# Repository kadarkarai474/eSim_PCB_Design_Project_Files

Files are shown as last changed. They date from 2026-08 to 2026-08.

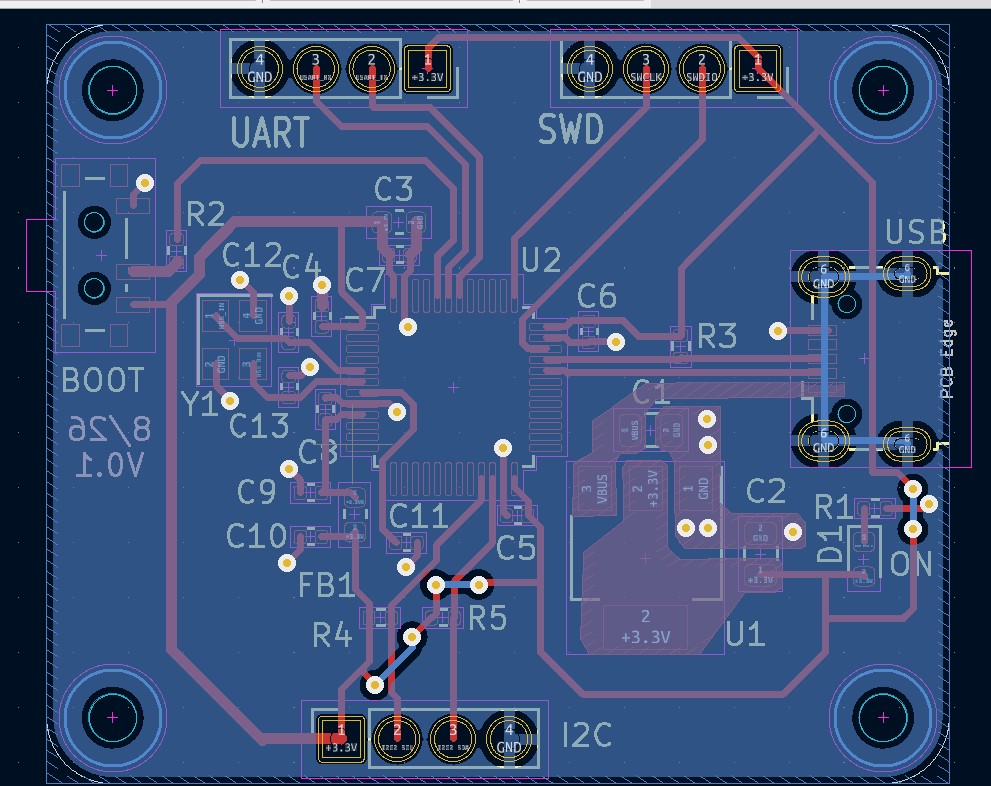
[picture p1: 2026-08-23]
PCB_IMAGES/Screenshot 2026-08-23 191847.jpg

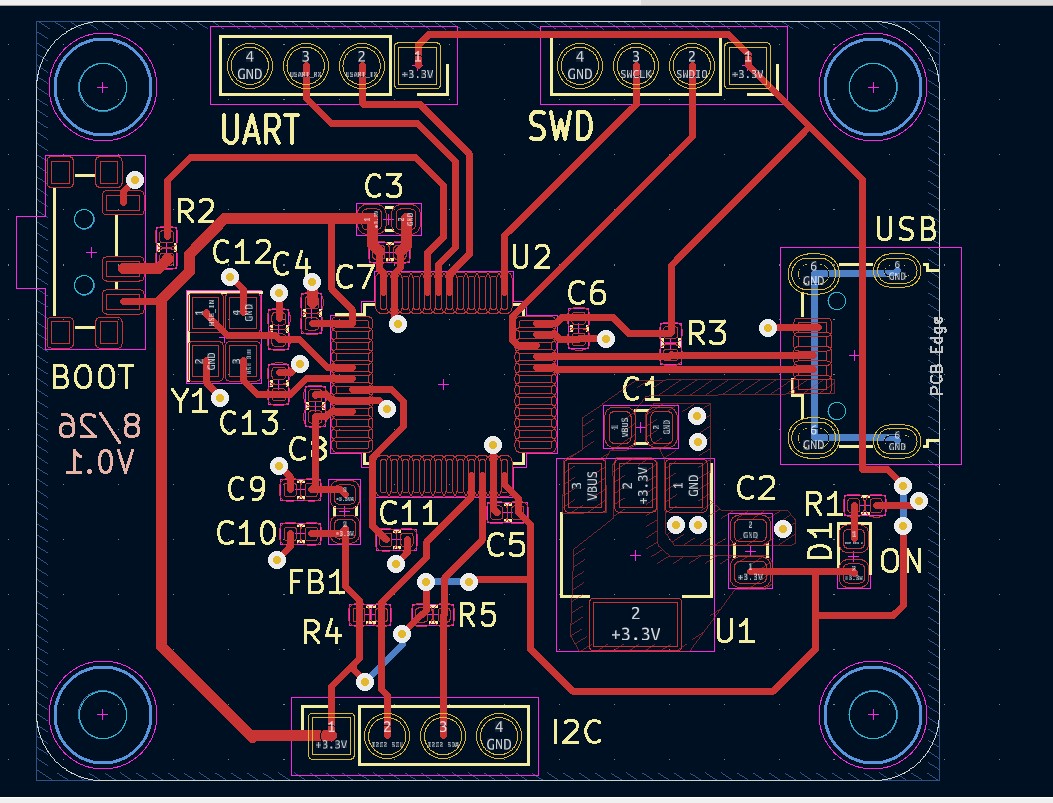
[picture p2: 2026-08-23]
PCB_IMAGES/Screenshot 2026-08-23 191208.jpg

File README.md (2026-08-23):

# STM32BASE — Custom STM32F103C8T6 USB Development and Multi-Interface Controller Board

## 1. Project Title

**STM32BASE: Custom STM32F103C8T6 USB Development and Multi-Interface Controller Board**

## 2. Project Abstract

STM32BASE is a compact, custom-designed STM32 microcontroller development and embedded-control board developed as a reusable hardware platform for embedded systems, IoT, robotics, instrumentation, and digital control applications. The board is centered around the **STM32F103C8T6 ARM Cortex-M3 microcontroller** and integrates regulated 3.3 V power, USB connectivity, UART communication, I²C expansion, SWD programming/debugging, boot-mode selection, external clock generation, status indication, and dedicated decoupling/filtering.

The proposed design converts the functionality normally distributed across a commercial STM32 development board, USB-to-serial interface board, and separate programming/debugging headers into a single custom PCB. The STM32F103 family provides high-performance processing with operation up to 72 MHz and peripherals including USB, USART, SPI, I²C, ADC, timers/PWM and CAN, making the platform suitable for extending the present design with additional communication and control interfaces.

The PCB is designed with attention to component placement, power distribution, short high-speed signal paths, grounding, decoupling, footprint selection, routing quality, and manufacturability. The current implementation is a **two-layer PCB**, satisfying the FOSSEE eSim PCB Design requirement of at least two copper layers; a future four-layer revision could further improve power/ground integrity and may receive additional consideration under the current Autumn 2026 evaluation criteria.

## 3. Problem Statement

Commercial STM32 development boards are convenient for prototyping but often contain unnecessary circuitry, limited connector options, and a fixed board architecture. For embedded development and PCB-design education, there is a need for a compact custom controller board that exposes essential MCU interfaces while demonstrating the complete engineering workflow from schematic capture to PCB layout, routing, DRC verification, and 3D visualization.

**STM32BASE addresses this requirement by providing a reusable custom STM32 platform with integrated programming, communication, power, clock, boot and expansion interfaces on a single PCB.**

## 4. Main Objectives

1. Design a functional custom STM32F103C8T6-based controller PCB.
2. Implement a stable **5 V to 3.3 V regulated power architecture**.
3. Provide direct USB connectivity for power and USB communication.
4. Provide dedicated UART, I²C and SWD connectors.
5. Implement a reliable external clock using an 8 MHz crystal.
6. Provide BOOT-mode selection for firmware programming and recovery.
7. Implement proper MCU decoupling and filtered power distribution.
8. Demonstrate practical PCB layout and routing techniques.
9. Perform electrical and design-rule verification before fabrication.
10. Develop the complete project using the eSim-compatible PCB workflow required by FOSSEE.

## 5. Functional Block Description

**USB / 5 V Input → Power Regulation → 3.3 V Digital Supply → STM32F103C8T6**

The MCU provides the central processing function and connects to:

**USB Interface → USB D+/D−**

**UART Header → Serial Communication**

**I²C Header → Sensor/Peripheral Expansion**

**SWD Header → Programming and Debugging**

**BOOT Selector → Firmware Boot Configuration**

**8 MHz Crystal → External Clock Reference**

**LED → Power/Status Indication**

## 6. Key Design Parameters

| Parameter | Proposed Design |
| --- | --- |
| Project Name | STM32BASE |
| MCU | STM32F103C8T6 |
| MCU Architecture | ARM Cortex-M3 |
| Maximum MCU Clock | Up to 72 MHz for STM32F103 performance-line devices |
| MCU Supply | 3.3 V nominal |
| MCU Supply Range | STM32F103 family: 2.0–3.6 V |
| Input Supply | 5 V from USB |
| Voltage Regulator | AMS1117-3.3 |
| Regulated Output | 3.3 V |
| External Crystal | 8 MHz |
| USB | USB 2.0 Full-Speed device interface |
| Programming | SWD |
| Serial Interface | UART |
| Sensor/Expansion Interface | I²C |
| Boot Configuration | BOOT selector |
| PCB Layers | 2-layer current design |
| Future PCB Option | 4-layer revision |
| Board Type | Custom STM32 development/controller board |
| PCB Technology | SMD + through-hole connectors |
| Mounting | Four PCB mounting holes |
| Status Indication | LED indicator |
| Debug Interface | SWD header |
| Expansion | UART and I²C headers |
| Primary Application | Embedded control and rapid prototyping |

## 7. Major Components Required

| Ref. | Component | Typical Value / Part | Quantity | Function |
| --- | --- | --- | ---: | --- |
| U2 | Microcontroller | STM32F103C8T6 | 1 | Main processing/control unit |
| U1 | LDO Regulator | AMS1117-3.3 | 1 | 5 V to 3.3 V regulation |
| J1 | USB Connector | Micro-USB | 1 | Power and USB data |
| J2 | UART Header | 1×4 header | 1 | UART TX/RX and power |
| J3 | I²C Header | 1×4 header | 1 | I²C SDA/SCL and power |
| J4 | SWD Header | 1×4 header | 1 | Programming/debugging |
| Y1 | Crystal | 8 MHz | 1 | External MCU clock |
| S1 | Boot Switch | SPDT | 1 | Boot-mode selection |
| FB1 | Ferrite Bead | Power filtering type | 1 | Supply-noise isolation |
| D1 | LED | 3.3 V status/power LED | 1 | Visual indication |
| R1 | LED Resistor | 1.5 kΩ | 1 | LED current limiting |
| R2 | BOOT Resistor | 10 kΩ | 1 | BOOT0 biasing |
| R3 | USB Resistor | 1 kΩ class | 1 | USB interface support |
| R4 | I²C Pull-up | 4.7 kΩ | 1 | SDA pull-up |
| R5 | I²C Pull-up | 4.7 kΩ | 1 | SCL pull-up |
| C1/C2 | Bulk Capacitors | 10–22 µF class | 2 | Supply stabilization |
| C3–C11  | Ceramic Decoupling | 100 nF / 1 µF / 10 µF class |  Several | MCU and supply decoupling |
| C12/C13 | Crystal Capacitors | ~10–20 pF class | 2 | Crystal load capacitors |
| H1–H4 | Mounting Hardware  | PCB mounting holes | 4 | Mechanical mounting |

**Note:** The final BOM should exactly match the verified eSim schematic values before submission. Values such as the USB support resistor and capacitor values should be checked against the final schematic/netlist rather than copied only from the PCB screenshot.

## 8. Interface Specification

| Interface | Connector | Purpose | Application |
| --- | --- | --- | --- |
| USB | Micro-USB | Power + USB data | PC communication / firmware tools |
| UART | 1×4 header | Serial TX/RX | Debugging, GPS, GSM, Bluetooth modules |
| I²C | 1×4 header | SDA/SCL | Sensors, displays, EEPROMs |
| SWD | 1×4 header | Programming/debugging | STM32 programmer/debugger |
| BOOT | SPDT switch | Boot configuration | Firmware recovery/programming |
| GPIO | MCU expansion capability | Digital control | LEDs, relays, sensors |
| ADC | MCU internal | Analog measurement | Sensors/potentiometers |
| PWM | MCU timers | Actuator control | Motors, LEDs, servos |

The STM32F103 family natively supports USB, USART, SPI, I²C, ADC, timers/PWM and CAN, providing a strong path for expanding this base platform into a more capable universal controller.

## 9. Power-Supply Architecture

The power section accepts **5 V from the USB connector** and generates a regulated **3.3 V rail** using an AMS1117-3.3 regulator.

| Stage | Component | Voltage | Purpose |
| --- | --- | ---: | --- |
| Input | USB VBUS | 5 V | External power source |
| Filtering | C1/C2 + FB1 | 5 V | Reduce supply disturbances |
| Regulation | AMS1117-3.3 | 3.3 V | MCU supply generation |
| Local Decoupling | Ceramic capacitors | 3.3 V | Suppress high-frequency noise |
| MCU Supply | STM32F103C8T6 | 3.3 V | Core and I/O supply |

The regulated 3.3 V supply is appropriate for the STM32F103 family, whose specified supply range is 2.0–3.6 V.

## 10. Clock and Reset Architecture

The design includes an **8 MHz external crystal oscillator** with dedicated load capacitors connected to the STM32 oscillator pins. The MCU can use its internal PLL to derive the required system clock from the external clock source.

The clock section is intentionally placed close to the MCU to reduce unnecessary trace length and susceptibility to noise.

The design also includes the required boot-selection circuitry, allowing the user to select normal firmware execution or the appropriate boot/programming mode.

## 11. PCB Design Features

The PCB layout shown in the design incorporates:

* Dedicated MCU placement near the center of the board.
* Compact placement of crystal and oscillator capacitors near the MCU.
* Dedicated USB connector at the board edge.
* Separate SWD and UART headers for convenient debugging.
* I²C expansion connector for external peripherals.
* Local decoupling capacitors surrounding the MCU.
* Separate power-regulation section.
* Ferrite filtering for supply-noise isolation.
* Clearly identifiable component reference designators.
* Four mechanical mounting holes.
* Ground and power routing designed around the major functional blocks.

## 12. PCB Routing Strategy

| Design Area | Routing Strategy |
| --- | --- |
| 3.3 V Power | Short, low-resistance power paths |
| MCU Decoupling | Capacitors placed as close as practical to supply pins |
| Crystal | Very short oscillator connections |
| USB | Short and symmetric D+/D− routing |
| SWD | Direct routing between MCU and debug header |
| UART | Direct low-speed signal routing |
| I²C | Pull-up resistors located on the interface section |
| Ground | Continuous/low-impedance ground strategy |
| USB Entry | Connector positioned at PCB edge |
| High-activity Signals | Kept away from sensitive clock section |
| Mechanical | Components kept clear of mounting-hole regions |

## 13. Important PCB Design Parameters

| Parameter | Design Target |
| --- | --- |
| PCB Layer Count | 2 layers |
| Recommended Future Version | 4 layers |
| Board Shape | Compact rectangular |
| Mounting Holes | 4 |
| Main PCB Material | FR-4 |
| Copper | Standard PCB copper |
| Component Technology | Predominantly SMD |
| Connectors | Through-hole/SMD depending on selected footprint |
| Ground Strategy | Dedicated ground routing/pour |
| DRC | Zero critical errors targeted |
| Routing | Complete connectivity |
| Silkscreen | Component identification and interface labels |
| 3D Verification | Required |
| Footprint Verification | Required |
| Manufacturing Readiness | Required |

## 14. Design Complexity

The project is more than a basic microcontroller breakout because it combines multiple hardware subsystems on a single custom PCB:

| Subsystem | Complexity |
| --- | --- |
| STM32 MCU integration | Medium |
| USB interface | Medium |
| 3.3 V power supply | Medium |
| External clock | Medium |
| BOOT configuration | Low–Medium |
| SWD programming | Low |
| UART expansion | Low |
| I²C expansion | Low |
| Power filtering | Medium |
| High-density MCU routing | High |
| Compact PCB placement | High |
| DRC and manufacturability | High |
| Complete eSim → PCB → 3D workflow | High |

This makes STM32BASE a **medium-to-hard complexity PCB project**, while remaining realistic to fabricate and demonstrate.

## 15. Advantages of the Proposed Design

1. **Custom rather than module-based:** The STM32 MCU is directly placed on the PCB instead of using a prebuilt development module.
2. **Integrated programming:** SWD is available directly on the board.
3. **USB-enabled:** A dedicated USB connector removes the need for an external USB interface board.
4. **Multiple communication interfaces:** UART and I²C are directly accessible.
5. **Dedicated power architecture:** USB input and regulated 3.3 V distribution are integrated.
6. **Expandable:** Unused STM32 peripherals can be exposed in future revisions.
7. **Educational value:** Demonstrates schematic design, footprint selection, power design, PCB placement, routing, DRC and 3D verification.
8. **Reusable platform:** The board can become the base controller for robotics, sensor nodes, automation systems and IoT prototypes.

## 16. Suggested Future Enhancements

To make a future revision more advanced and competitive, the following can be added:

| Enhancement | Benefit |
| --- | --- |
| CAN transceiver | Automotive/industrial communication |
| SPI header | High-speed peripheral expansion |
| Additional GPIO headers | External module integration |
| ADC expansion header | Analog sensor interfacing |
| PWM header | Motor/servo control |
| 5 V output | External module power |
| ESD protection on USB | Improved robustness |
| Reverse-polarity protection | Safer external power |
| Reset/user push button | Improved user interaction |
| Additional status LEDs | Easier debugging |
| USB ESD protection | Better USB reliability |
| 4-layer PCB | Improved power/ground integrity and routing density |
| Dedicated ground plane | Better return-current control |
| Test points | Easier laboratory debugging |

## 17. FOSSEE eSim PCB Design Relevance

This project directly demonstrates the workflow expected for the current FOSSEE eSim PCB Design task: schematic development, footprint assignment, PCB generation, routing, DRC verification and 3D visualization. The Autumn 2026 task specifies a minimum of two copper layers and notes that boards with a higher layer count may receive additional consideration. It also evaluates design complexity, footprint assignment, layout quality, routing practices, DRC validation, eSim compatibility and documentation quality.

The final submission should therefore document the complete design flow rather than presenting only the finished PCB.

## 18. Expected Deliverables

| Deliverable | Contents |
| --- | --- |
| Schematic | Complete STM32BASE circuit |
| PCB | Routed PCB layout |
| Project Files | Complete eSim/KiCad-compatible project |
| BOM | Components, values, quantities and footprints |
| Schematic Images  | Annotated circuit diagrams |
| PCB Images | Top/bottom/layout views |
| 3D Images | Final PCB 3D visualization |
| DRC Report | Verification and corrected errors |
| Design Report | Architecture, design decisions and results |
| Execution Guide | Steps to open and verify the project |
| GitHub Repository | Organized project source and documentation |

FOSSEE's current Autumn 2026 PCB-design instructions specifically require a detailed PDF report, complete eSim project workspace, instructions for opening/verifying the project, and optionally a short presentation or demonstration.

## 19. Proposed Applications

STM32BASE can be used as the central controller for:

* IoT sensor nodes
* Industrial monitoring
* Robotics controllers
* Motor-control prototypes
* Environmental monitoring
* Data acquisition systems
* Smart automation
* Embedded instrumentation
* Communication gateways
* Educational STM32 development
* Custom sensor and actuator platforms

## 20. Conclusion

**STM32BASE is a compact custom STM32 development and controller platform that integrates the essential hardware required for embedded development into a single PCB.** The design combines a regulated 3.3 V power system, STM32F103C8T6 microcontroller, USB connectivity, UART, I²C, SWD programming, external clock, BOOT control, filtering, status indication and mechanical mounting into one reusable board.

The project provides substantial PCB-design content while remaining technically manageable: the evaluator can clearly observe the schematic architecture, power design, footprint selection, dense MCU routing, interface placement, DRC verification and final 3D implementation. It is therefore a strong candidate for an eSim/FOSSEE PCB Design submission, with a clear path toward a more advanced four-layer revision incorporating CAN, SPI, additional GPIO/PWM/ADC expansion and improved protection circuitry.

### Recommended Final Project Name

**STM32BASE – Custom STM32F103C8T6 USB Multi-Interface Development and Control Board**

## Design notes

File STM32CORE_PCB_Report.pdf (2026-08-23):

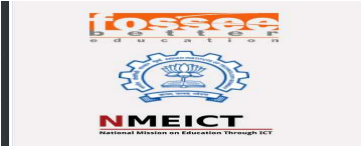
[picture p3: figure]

## FOSSEE 2026 - SEMESTER LONG INTERNSHIP

## INTERNSHIP SCREENING TASK REPORT

### Task 7 — PCB Design using eSim KICAD

## Prepared by Kadarkarai V, II Year

## Department of VLSI Design and Technology Chennai Institute of Technology

### PROJECT: STM32BASE — Custom STM32F103C8T6 USB Development and Multi-Interface Controller Board

STM32CORE — PCB Design Report

## 1. Project Overview

This project presents the complete printed circuit board (PCB) design and schematic files for a custom STM32F103C8T6 microcontroller development and interface board, named STM32CORE. The design was developed as part of the screening task for the FOSSEE Autumn Internship 2026 program conducted by IIT Bombay.

The primary objective of this project was to design a compact, functional, and manufacturable controller board centered around the STM32F103C8T6 (Cortex-M3) microcontroller, integrating regulated power, USB connectivity, UART communication, I²C expansion, SWD programming, boot-mode selection, and an external crystal clock reference onto a single custom two-layer PCB.

Key Project Details

Category | Specification / Detail
Microcontroller | STM32F103C8T6 / STM32F103CBTx (ARM Cortex-M3, up to 72 MHz)
Design Tools | eSim 5 (schematic capture), KiCad 6 (PCB layout, integrated via eSim)
Input Supply | 5 V from USB (VBUS)
Regulated Supply | 3.3 V, via AMS1117-3.3 LDO regulator
Crystal Oscillator | 16 MHz external crystal
PCB Stackup | 2-layer (Front Copper + Back Copper)
Verification Status | Both ERC and DRC passed with zero errors
The finished design includes a fully routed two-layer PCB, verified schematic with zero ERC violations, a zero-violation DRC report, and a 3D rendered model for visual verification of component placement and mechanical fit.

## 2. Circuit Description

### 2.1 Power Supply Section

The board is powered from the 5 V USB VBUS rail and regulated down to a stable 3.3 V supply using an AMS1117-3.3 LDO regulator (U1). Bulk input and output capacitors (C1, C2 — 22 µF each) stabilise the supply on both sides of the regulator, and a status LED (D1) with a 1.5 kΩ current-limiting resistor (R1) provides visual power-on indication.

### 2.2 Clock and Reset

A 16 MHz external crystal (Y1) with a pair of 10 pF load capacitors (C12, C13) provides the primary system clock reference to the STM32F103 oscillator pins (PD0/PD1). The MCU's internal PLL derives the required core clock from this external source. A dedicated reset line (NRST) and BOOT0 configuration network (R2, SW1) allow selection between normal firmware execution and system bootloader mode for programming/recovery.

### 2.3 Connectivity and Interfaces

- Micro-USB Port (J1): USB 2.0 Full-Speed interface for power and USB D+/D− data, with a 1.5 kΩ series resistor (R3) on the data line as per USB application guidelines.
- SWD Header (J3): 4-pin header exposing SWDIO, SWCLK, 3.3 V and GND for direct on-board programming and debugging.
- UART Header (J2): 4-pin header exposing USART_TX, USART_RX, 3.3 V and GND for serial communication and debugging.
- I²C Header (J4): 4-pin header exposing I2C2_SDA, I2C2_SCL, 3.3 V and GND, with 1.5 kΩ pull-up resistors (R4, R5) for sensor and peripheral expansion.

### 2.4 Power Filtering and Decoupling

The analog supply (VDDA) is isolated from the digital 3.3 V rail using a 120 Ω ferrite bead (FB1) with local filter capacitors (C8, C9, C10), reducing high-frequency supply noise reaching the MCU's analog section. Digital decoupling is provided at the MCU supply pins using a bank of ceramic capacitors (C3–C7: 10 µF and 100 nF values) placed close to the VDD/VBAT pins.

### 2.5 Peripheral Summary

Interface | Header / Pins | Typical Application
USB | Micro-USB (J1), USB D+/D− | PC communication, firmware/programming tools
UART | J2 — USART_TX, USART_RX | Debugging, GPS, GSM, Bluetooth modules
I²C | J4 — SDA, SCL | Sensors, displays, EEPROMs
SWD | J3 — SWDIO, SWCLK | STM32 programmer / debugger
BOOT | SW1 (SPDT) + R2 | Firmware boot-mode / recovery selection

## 3. Schematic Screenshots

The complete schematic was designed in eSim 5 and organised into two logical, clearly labelled functional blocks — Power Supply and Microcontroller with USB — for clarity and maintainability.

### 3.1 Full Schematic Overview

The top-level schematic sheet (STM32BASE_DESIGN) provides a complete view of the design, showing the Power Supply block and the Microcontroller-with-USB block interconnected through labelled nets and power buses, along with the board mounting-hole reference symbols.

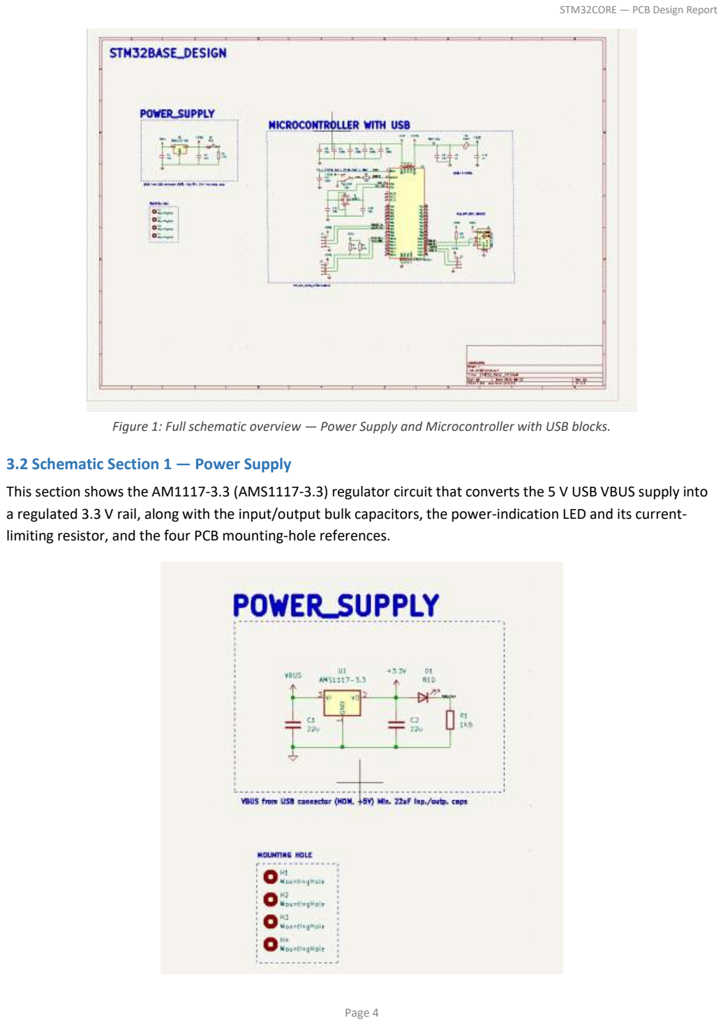
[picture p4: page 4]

Figure 1: Full schematic overview — Power Supply and Microcontroller with USB blocks.

### 3.2 Schematic Section 1 — Power Supply

This section shows the AM1117-3.3 (AMS1117-3.3) regulator circuit that converts the 5 V USB VBUS supply into a regulated 3.3 V rail, along with the input/output bulk capacitors, the power-indication LED and its current-limiting resistor, and the four PCB mounting-hole references.

Figure 2: Power Supply schematic — AMS1117-3.3 regulation and mounting-hole references.

### 3.3 Schematic Section 2 — Microcontroller with USB

This section captures the STM32F103CBTx pin assignments, the full decoupling capacitor network, the 16 MHz crystal oscillator connections, NRST/BOOT0 configuration circuitry, the VDDA filtering network, and the USB, UART and I²C interface connections — all cross-referenced against the STM32CubeIDE pin-out.

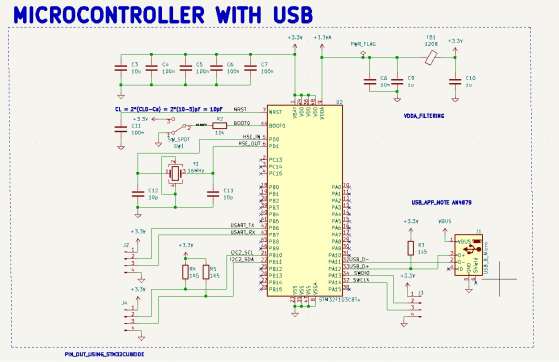
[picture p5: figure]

Figure 3: Microcontroller with USB — MCU core, clock, boot, and interface circuitry.

### 3.4 Electrical Rules Check (ERC)

The Electrical Rules Checker was run on the complete schematic in eSim/KiCad and returned zero violations, confirming that all nets, power pins, and interface connections are electrically consistent.

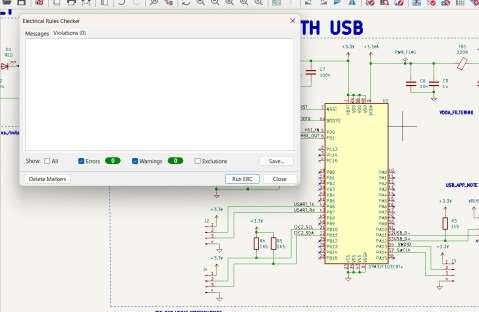
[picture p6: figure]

Figure 4: Electrical Rules Checker — 0 errors, 0 warnings.

## 4. Footprint Assignment Details

Component footprints were assigned in KiCad 6 using standard, datasheet-verified footprint libraries appropriate to each package type, ensuring correct pad geometry and courtyard clearances for fabrication.

### 4.1 Microcontroller

- Component: STM32F103C8T6 / STM32F103CBTx
- Package: LQFP-48, 7×7 mm body, 0.5 mm pin pitch

### 4.2 Passive Components

- Resistors: 0603 SMD footprint — used for pull-ups (I²C), current limiting (LED, BOOT0), and USB series termination
- Capacitors: 0603 SMD footprint — used for decoupling, bulk bypass, VDDA filtering, and crystal load capacitors
- Crystal Oscillator: SMD 2-pin/4-pin package as per component datasheet (16 MHz)

### 4.3 Connectors

- Micro-USB: Standard Micro-B USB receptacle footprint with mechanical shield/anchor pads
- Pin Headers (UART, SWD, I²C): 1×4, 2.54 mm pitch through-hole male headers

### 4.4 Power and Interface Components

- Voltage Regulator (AMS1117-3.3): SOT-223 footprint with thermal pad
- Boot Selector: SPDT slide/tactile switch footprint
- Status LED: 0603 SMD LED footprint

## 5. PCB Layout

The PCB layout was completed in KiCad 6 (accessed through eSim 5 integration) as a two-layer board, with the Front Copper (F.Cu) layer carrying the primary component-side routing and the Back Copper (B.Cu) layer used for return paths and selective routing.

### 5.1 Complete Board — Routed Layout

The routed board places the STM32F103 MCU (U2) centrally, with the crystal and its load capacitors kept close to the oscillator pins, the USB connector positioned at the board edge, and the UART, SWD and I²C headers broken out along the top and bottom edges for easy access. Four mechanical mounting holes are provided at the corners.

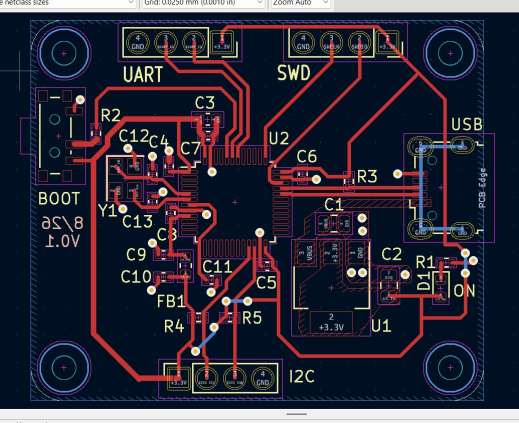
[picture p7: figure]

Figure 5: Complete routed PCB layout — top view showing UART, SWD, USB, I²C and BOOT sections.

### 5.2 Board Layout — Alternate Layer View

This view highlights the copper routing on the board with the alternate KiCad colour theme, showing the same interconnects between the MCU, power section (U1, C1, C2), filtering network (FB1, R4, R5) and the four peripheral headers.

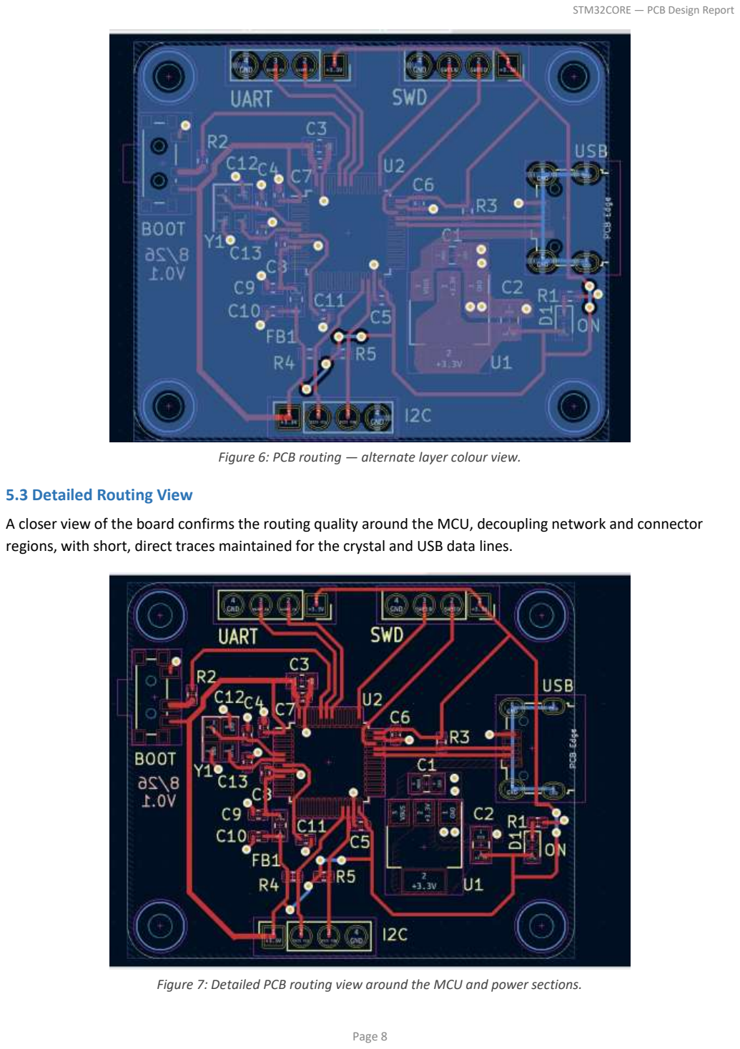
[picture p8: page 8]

Figure 6: PCB routing — alternate layer colour view.

### 5.3 Detailed Routing View

A closer view of the board confirms the routing quality around the MCU, decoupling network and connector regions, with short, direct traces maintained for the crystal and USB data lines.

Figure 7: Detailed PCB routing view around the MCU and power sections.

## 6. Routing Methodology

### 6.1 Layer Stackup

Layer | Name | Function
1 | F.Cu (Front) | Primary component-side signal routing
2 | B.Cu (Back) | Secondary routing and return paths

### 6.2 Signal Routing Guidelines

- Decoupling capacitors placed as close as physically possible to the MCU VDD/VBAT pins.
- Crystal oscillator traces routed short and direct, with the crystal and load capacitors kept close to the MCU oscillator pins to minimise parasitic capacitance.
- USB D+/D− lines routed as a short, symmetric pair from the MCU to the Micro-USB connector at the board edge.
- I²C pull-up resistors located directly at the I²C header for signal integrity.
- General signal traces routed on the front copper layer with return paths managed on the back copper layer.
- Components kept clear of the four mounting-hole regions for mechanical safety.

### 6.3 Design Rule Constraints

- Minimum trace width and spacing as per standard two-layer manufacturing capability.
- Minimum via drill size and annular ring maintained within manufacturer tolerances.
- Copper-to-edge clearance maintained around the full board outline.
- No acid traps or acute-angle traces present in the routing.

## 7. DRC Results

The Design Rules Check was performed on the completed two-layer PCB layout in KiCad 6 to verify physical manufacturability. All copper zones were refilled before running the check.

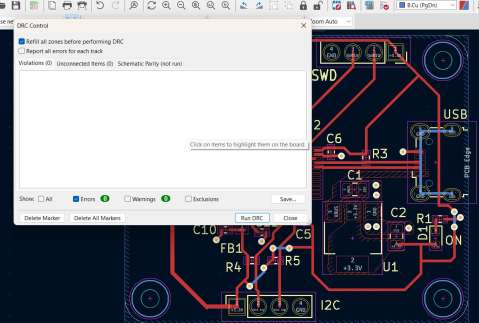
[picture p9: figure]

Figure 8: DRC Control — 0 violations, 0 unconnected items.

The DRC report confirms zero violations across errors, warnings and unconnected items, indicating that all traces, vias, clearances, and drill holes are within standard manufacturing capability.

## 8. 3D Model

The 3D model of the board was generated using KiCad's built-in 3D viewer to verify component placement accuracy, connector accessibility, and overall board form factor before committing to fabrication.

### 8.1 Front View

The front (top) view shows the primary component side of the board, with the STM32 MCU (U2) at the centre, surrounded by the crystal (Y1), decoupling capacitors, the BOOT switch, the regulator section (U1), and the UART, SWD, USB and I²C connectors clearly labelled on the silkscreen.

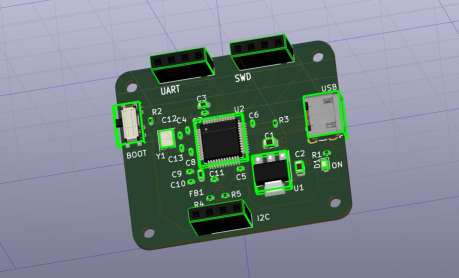
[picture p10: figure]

Figure 9: 3D model — front view with labelled interfaces.

### 8.2 Back View

The back (bottom) view shows the underside of the board, including the header through-hole pads, the version/date silkscreen marking (8/26, V0.1), and the mounting-hole positions.

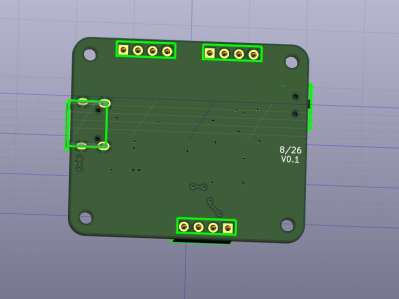
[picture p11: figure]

Figure 10: 3D model — back view.

## 9. Design Considerations and Conclusion

### 9.1 Design Considerations

Power Integrity: Bulk capacitors at the regulator input/output and a dedicated decoupling bank at the MCU supply pins keep the 3.3 V rail stable under load.

Signal Integrity: Short, direct routing for the crystal and USB data lines minimises parasitic effects and preserves clock accuracy and USB signal quality on a two-layer stackup.

Analog Isolation: The VDDA filtering network (FB1 ferrite bead with local capacitors) isolates the MCU's analog supply from digital switching noise.

Manufacturability: The design satisfies the FOSSEE eSim PCB Design requirement of a minimum of two copper layers, and passes DRC with zero errors, confirming that all features are within standard manufacturing capability.

Expandability: Unused STM32F103 peripherals (SPI, additional ADC/timer channels, CAN) remain available for a future, more advanced revision of the board.

### 9.2 Conclusion

This project successfully delivers a complete, verified PCB design for the STM32CORE development and interface board built around the STM32F103C8T6 microcontroller. The design achieves the following key outcomes:

- Fully verified design — ERC passed with zero violations, and DRC passed with zero errors and zero unconnected items.
- Compact two-layer stackup — meeting the FOSSEE eSim PCB Design minimum layer requirement while remaining realistic to fabricate.
- Comprehensive connectivity — the board exposes USB, UART, I²C and SWD through accessible headers, along with BOOT-mode selection.
- Complete documentation — schematic, PCB layout, ERC/DRC verification and 3D visualisation are all included for full design transparency.
The design demonstrates proficiency in schematic capture, PCB layout and routing, design-rule compliance, and 3D visualisation using eSim 5 and KiCad 6 — the core competencies required for the FOSSEE Autumn Internship 2026 screening task.
Designed by Kadarkarai V | Department of VLSI Design and Technology, Chennai Institute of Technology | FOSSEE Autumn
Internship 2026 — IIT Bombay

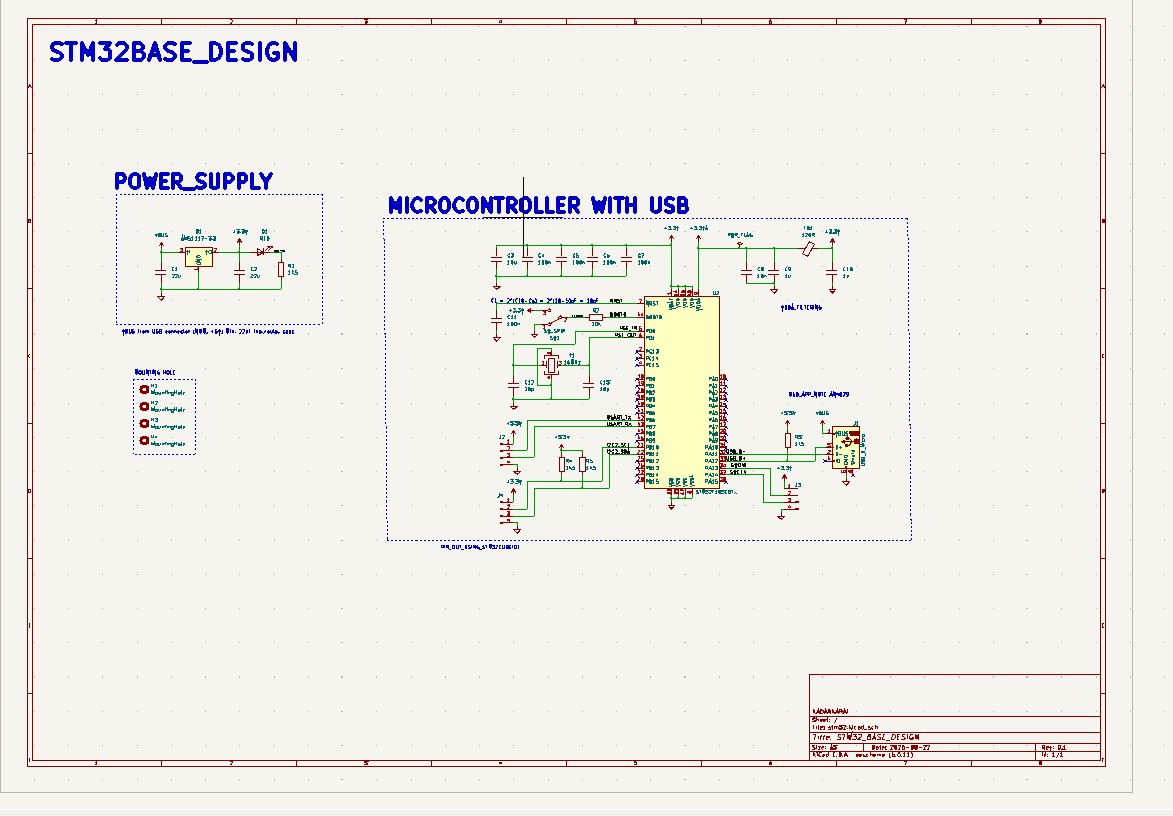
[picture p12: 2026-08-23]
PCB_IMAGES/Screenshot 2026-08-23 191109.jpg

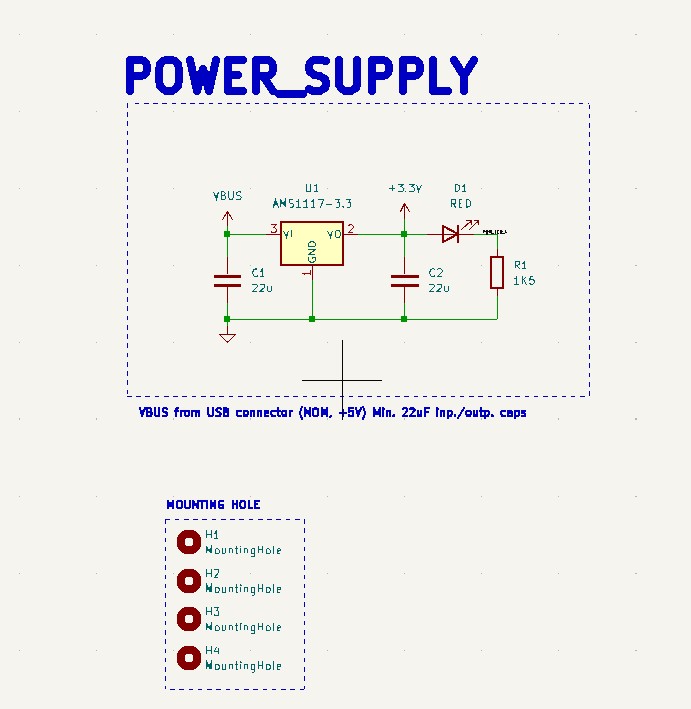
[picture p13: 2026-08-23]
PCB_IMAGES/Screenshot 2026-08-23 191127.jpg

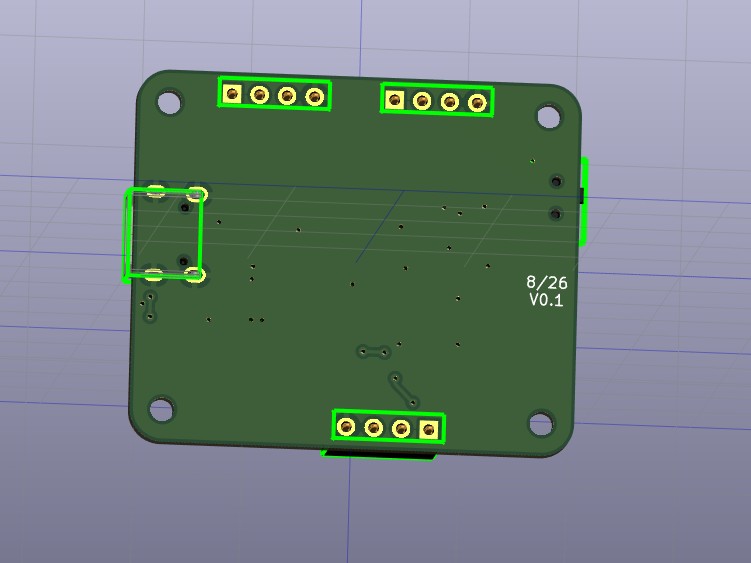
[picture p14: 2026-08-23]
PCB_IMAGES/Screenshot 2026-08-23 191251.jpg

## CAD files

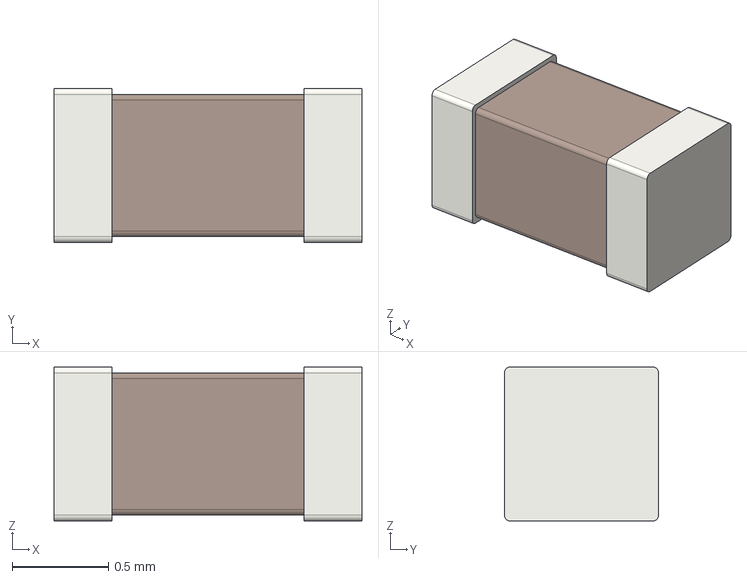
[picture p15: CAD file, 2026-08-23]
3DMODELS/C_0603_1608Metric.step
1.60 x 0.8 x 0.8 mm

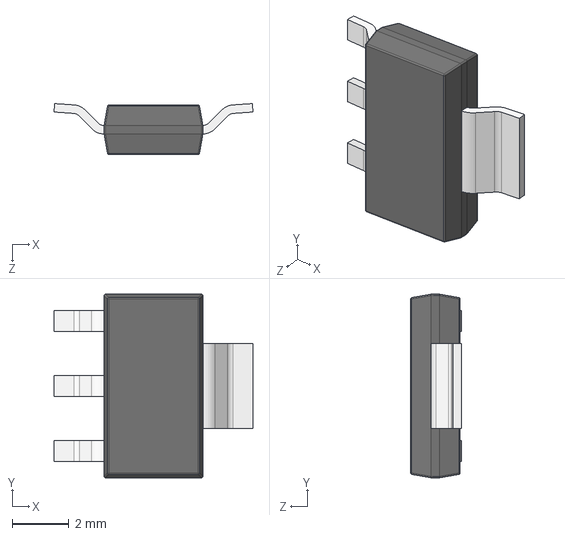
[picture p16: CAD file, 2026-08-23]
3DMODELS/SOT230P700X180-4N_JEDEC_TO-261AA_SOT223-3.STEP/SOT230P700X180-4N_JEDEC_TO-261AA_SOT223-3.STEP
7.04 x 6.50 x 1.80 mm

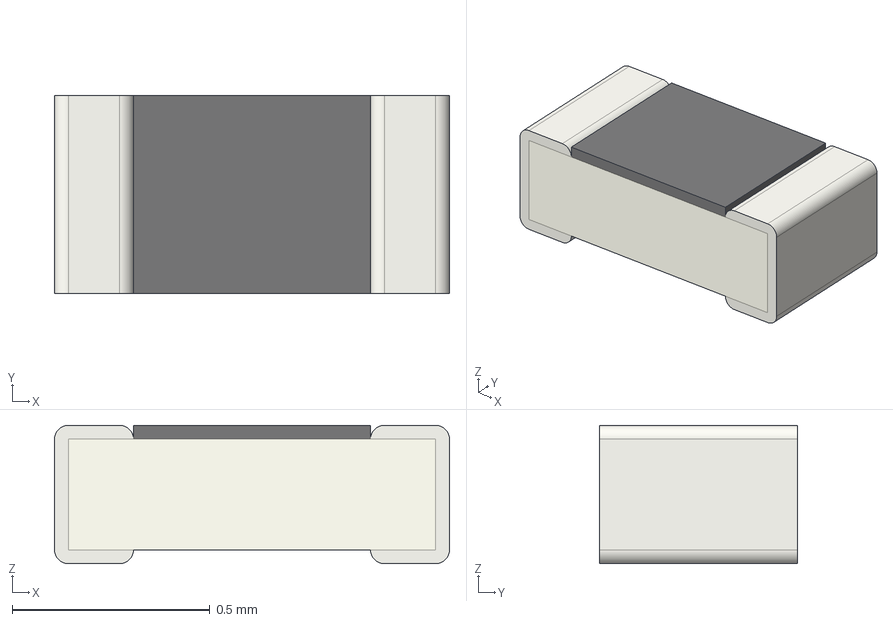
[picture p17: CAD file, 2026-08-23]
3DMODELS/R_0402_1005Metric.step
1.00 x 0.5 x 0.35 mm

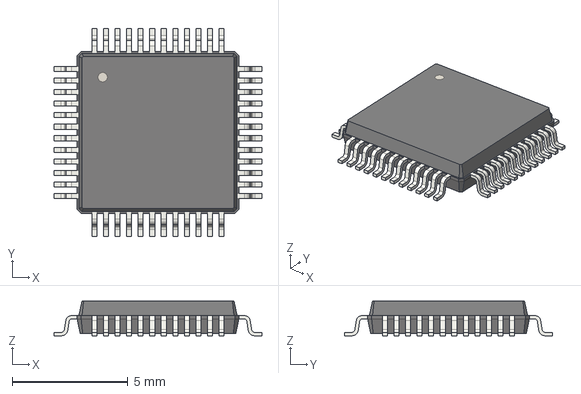
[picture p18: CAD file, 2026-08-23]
3DMODELS/LQFP-48_7x7mm_P0.5mm.step
9.00 x 9.00 x 1.50 mm

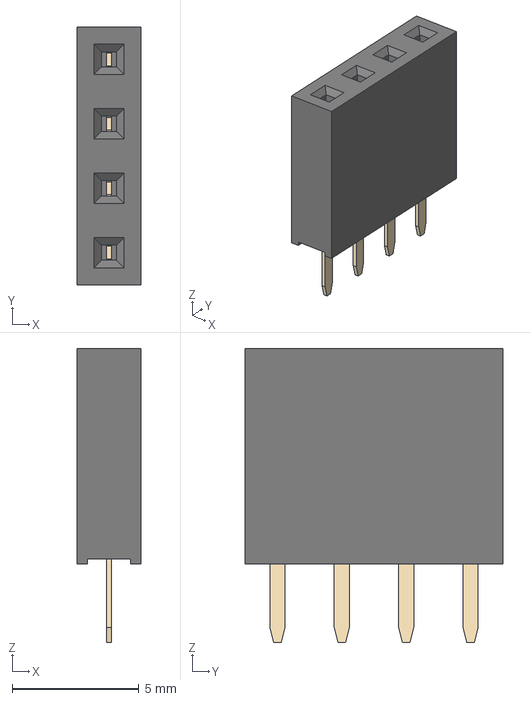
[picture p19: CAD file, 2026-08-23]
3DMODELS/PinSocket_1x04_P2.54mm_Vertical.step
2.54 x 10.2 x 11.6 mm

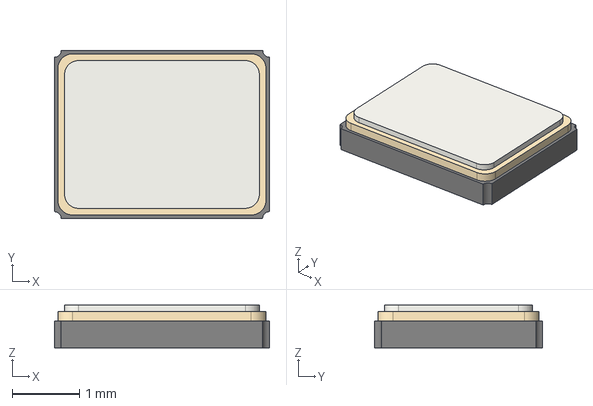
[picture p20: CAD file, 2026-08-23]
3DMODELS/Crystal_SMD_3225-4Pin_3.2x2.5mm.step
3.20 x 2.50 x 0.64 mm

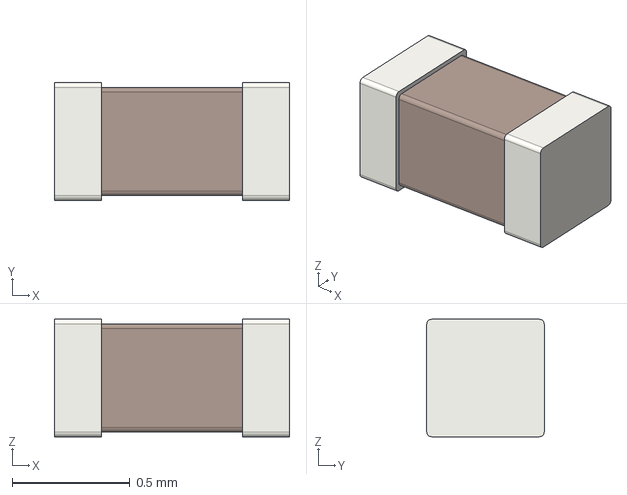
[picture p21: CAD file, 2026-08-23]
3DMODELS/C_0402_1005Metric.step
1.00 x 0.5 x 0.5 mm

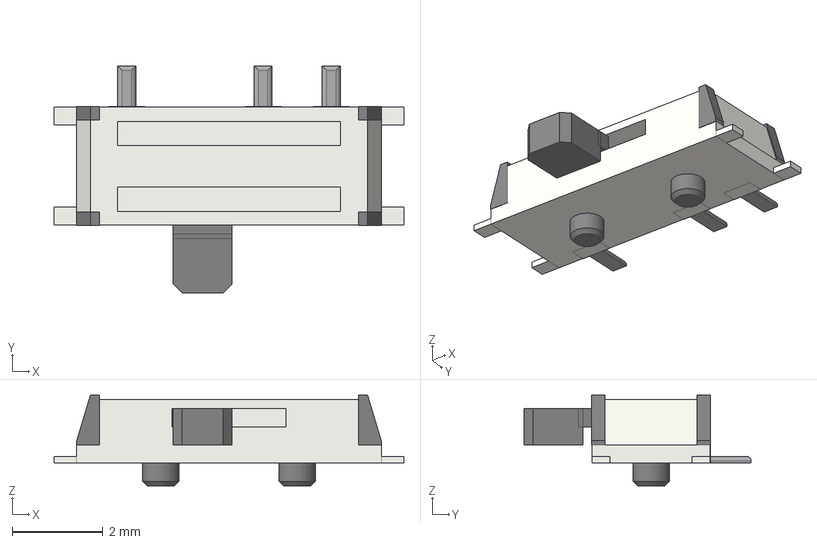
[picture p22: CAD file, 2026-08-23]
3DMODELS/SW_SPDT_PCM12.step
7.70 x 5.00 x 2.00 mm

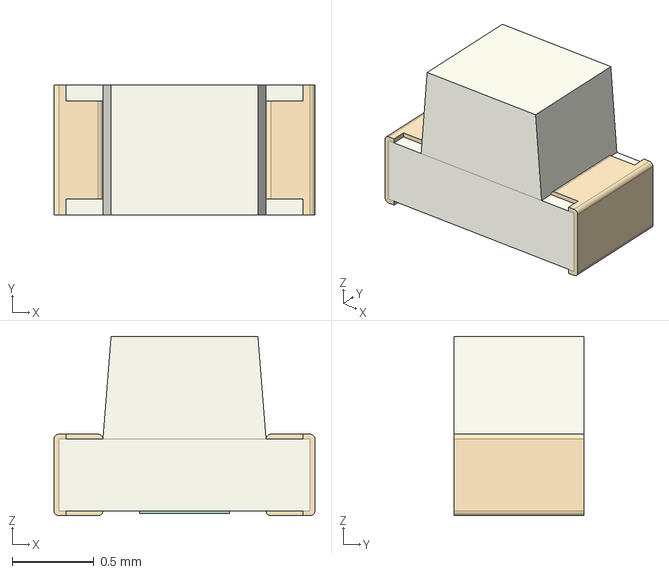
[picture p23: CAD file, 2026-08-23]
3DMODELS/LED_0603_1608Metric.step
1.60 x 0.8 x 1.10 mm

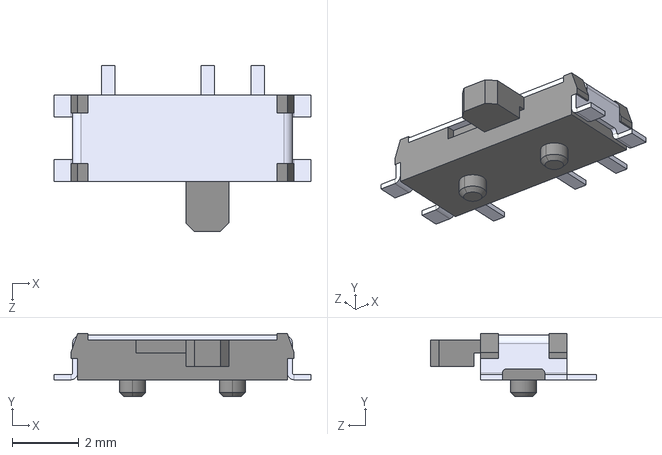
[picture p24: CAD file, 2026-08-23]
3DMODELS/PCM12SMTR.STEP
7.72 x 1.91 x 4.98 mm

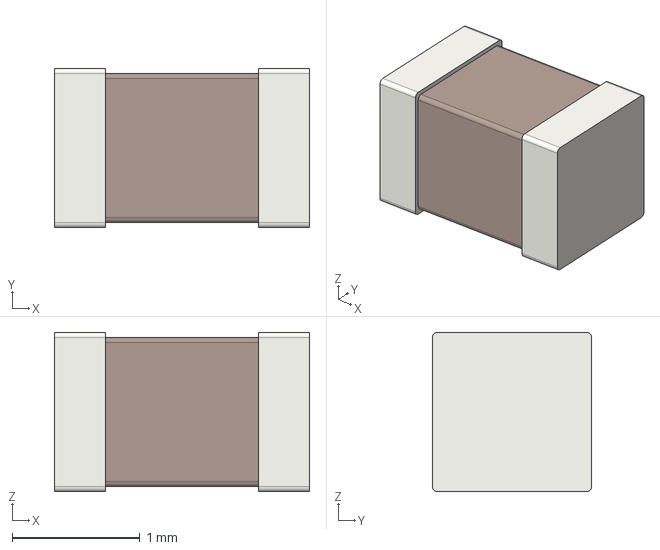
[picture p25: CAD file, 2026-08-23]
3DMODELS/C_0805_2012Metric.step
2.00 x 1.25 x 1.25 mm

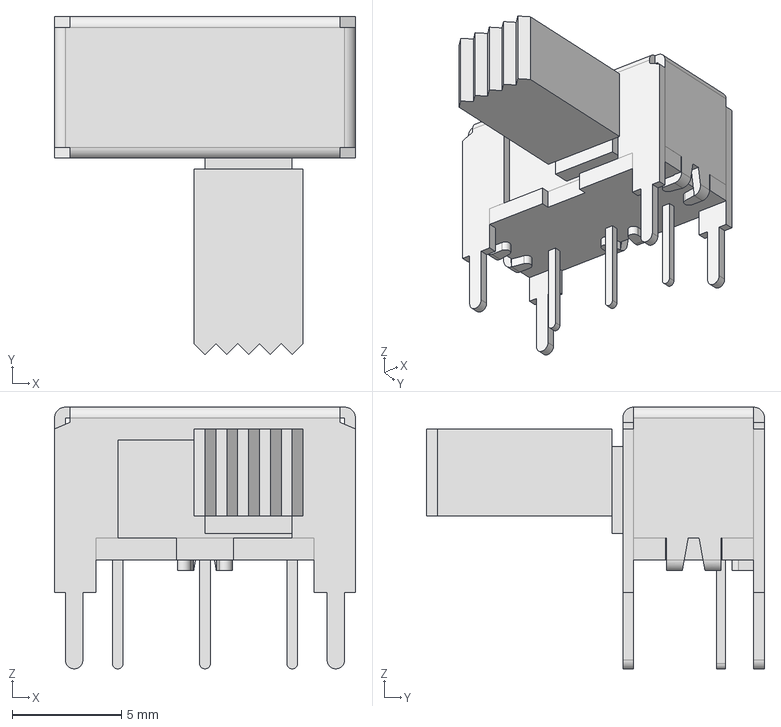
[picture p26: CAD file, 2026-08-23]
3DMODELS/EG1224.stp
13.8 x 15.5 x 12.0 mm

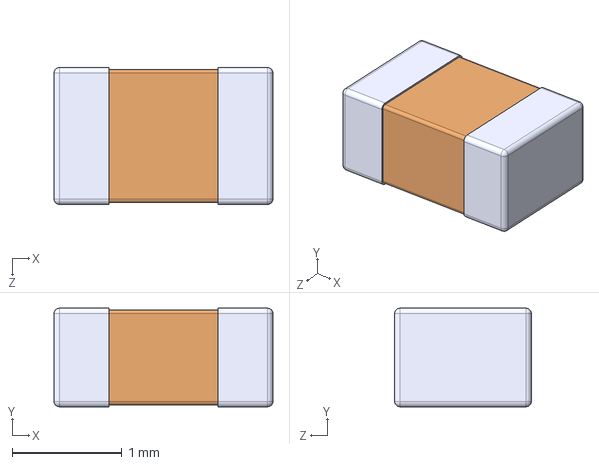
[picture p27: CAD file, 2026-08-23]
3DMODELS/VJ0805Y104KXXCW1BC.STEP
2.00 x 0.9 x 1.25 mm

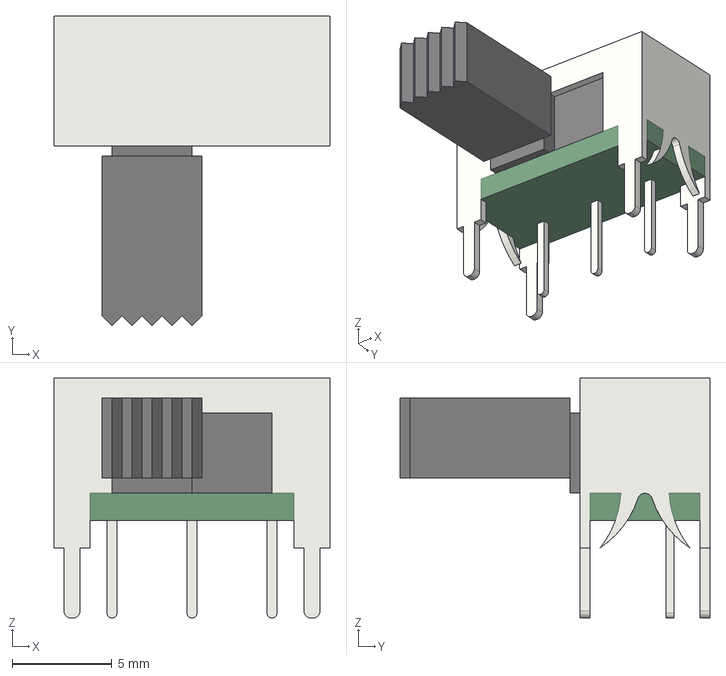
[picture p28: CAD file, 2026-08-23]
3DMODELS/SW_E-Switch_EG1224_SPDT_Angled.step
13.8 x 15.5 x 12.0 mm

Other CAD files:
3DMODELS/L_0603_1608Metric.step
3DMODELS/629105150521_20_28rev1_29.stp

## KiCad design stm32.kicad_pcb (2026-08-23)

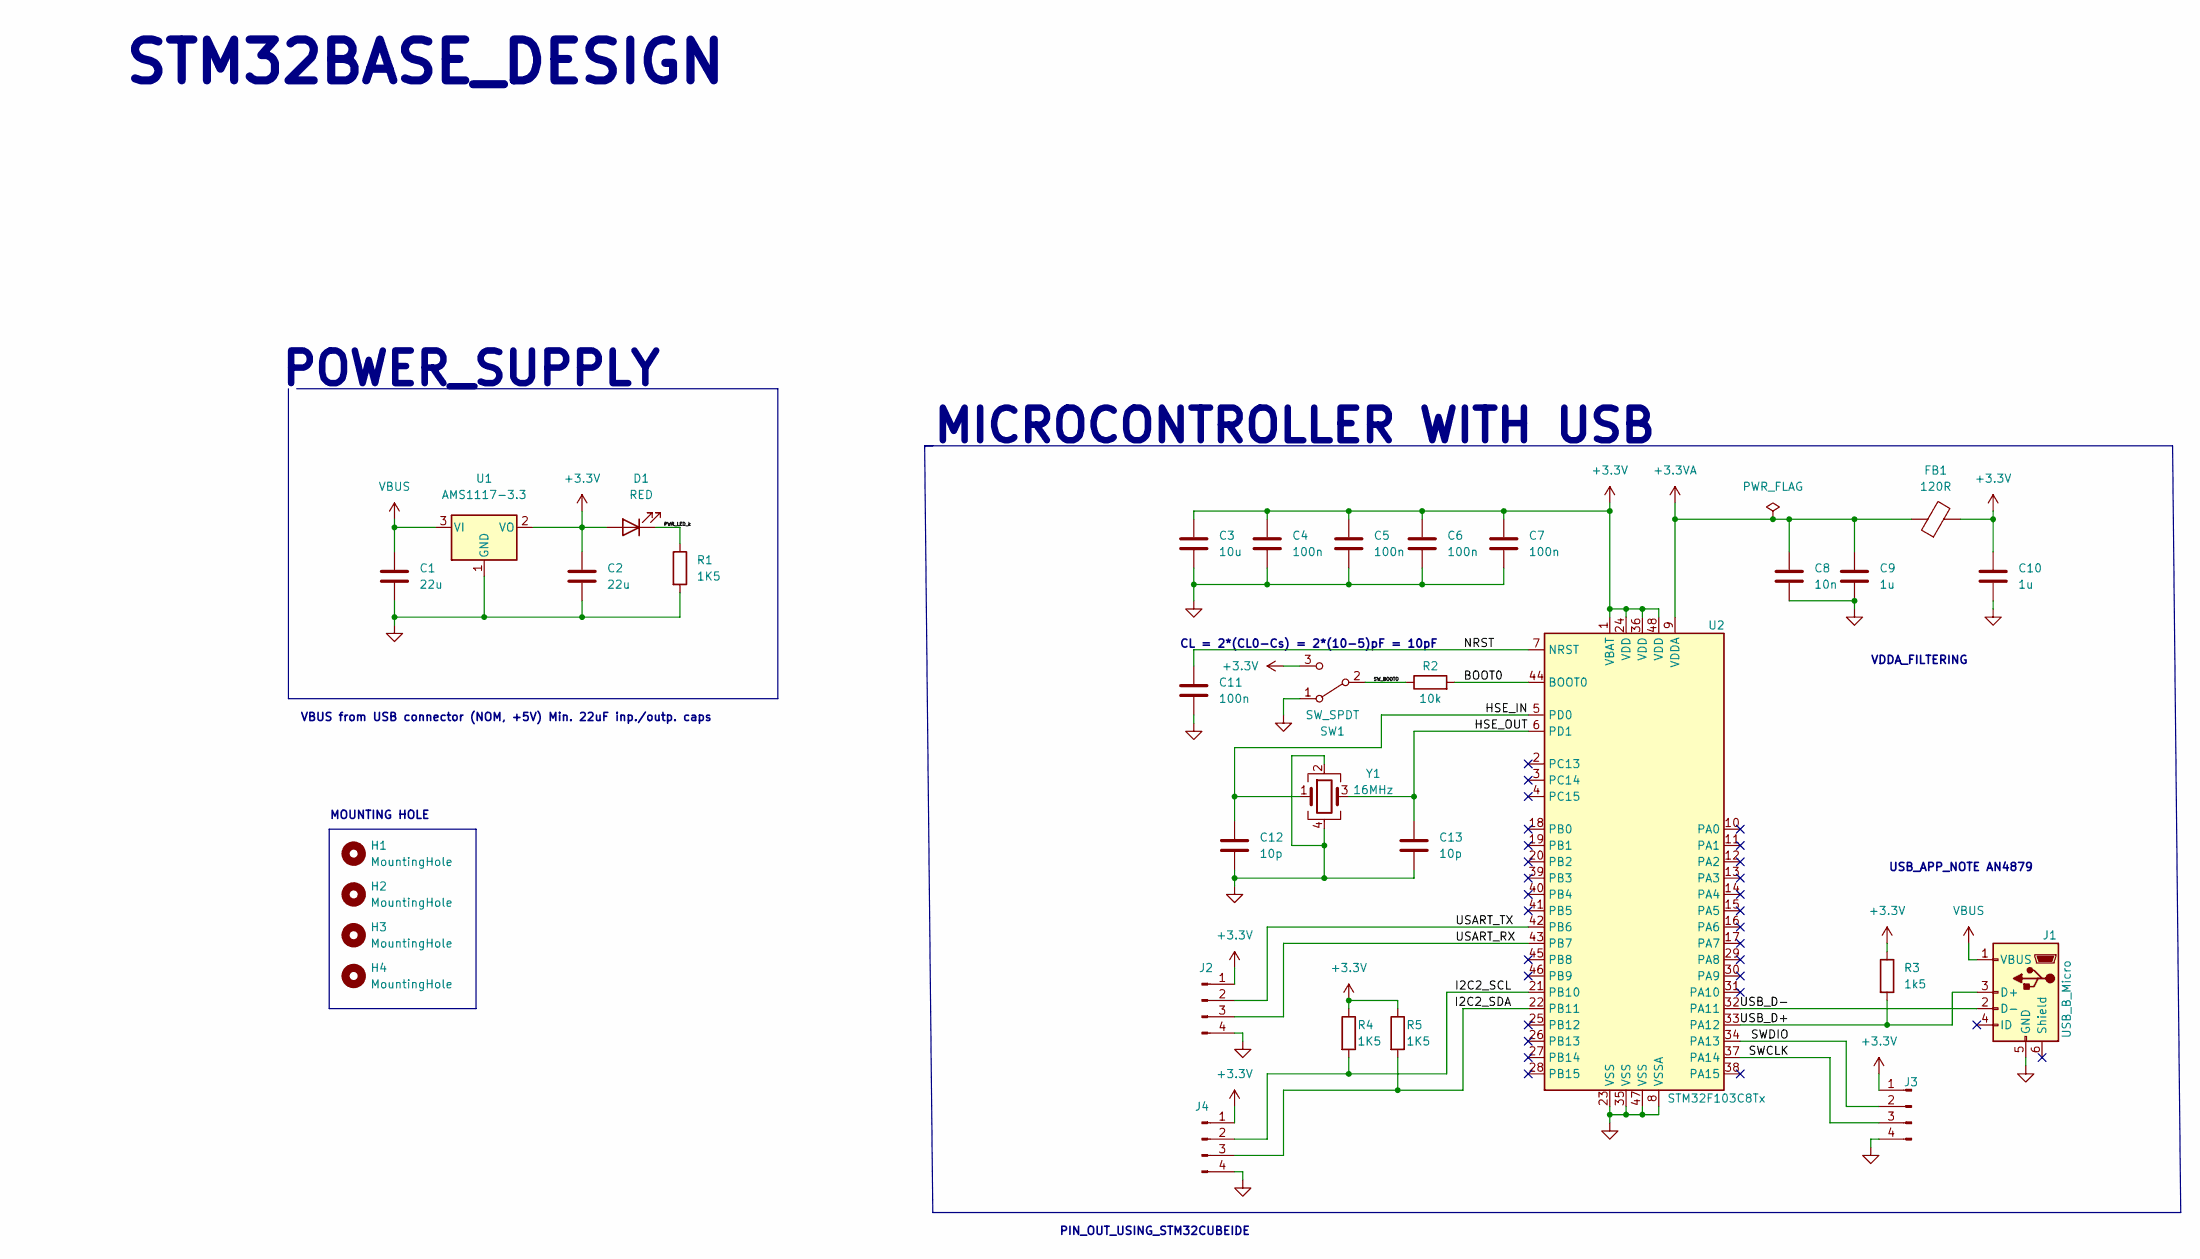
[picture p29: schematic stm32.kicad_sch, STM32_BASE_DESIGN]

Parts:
C1, C2: 22u; C_0805_2012Metric
C3: 10u; C_0603_1608Metric
C4, C5, C6, C7, C11: 100n; C_0402_1005Metric
C8: 10n; C_0402_1005Metric
C9, C10: 1u; C_0402_1005Metric
C12, C13: 10p; C_0402_1005Metric
D1: RED; LED_0603_1608Metric
FB1: 120R; L_0603_1608Metric
H1, H2, H3, H4: MountingHole; MountingHole_2.2mm_M2
J1: USB_B_Micro; USB_Micro-B_Wuerth_629105150521
J2, J3, J4: Conn_01x04_Male; PinSocket_1x04_P2.54mm_Vertical
R1, R4, R5: 1K5; R_0402_1005Metric
R2: 10k; R_0402_1005Metric
R3: 1k5; R_0402_1005Metric
SW1: SW_SPDT; SW_SPDT_PCM12
U1: AMS1117-3.3; SOT-223-3_TabPin2
U2: STM32F103C8Tx; LQFP-48_7x7mm_P0.5mm
Y1: 16MHz; Crystal_SMD_3225-4Pin_3.2x2.5mm

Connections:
+3.3V: C2.1, C3.1, C4.1, C5.1, C6.1, C7.1, C10.1, D1.2 (A), FB1.2, J2.1, J3.1, J4.1, R3.1, R4.1, R5.1, SW1.3 (C), U1.2 (VO), U2.1 (VBAT), U2.24 (VDD), U2.36 (VDD), U2.48 (VDD)
+3.3VA: C8.1, C9.1, FB1.1, U2.9 (VDDA)
/BOOT0: R2.2, U2.44 (BOOT0)
/HSE_IN: C12.1, U2.5 (PD0), Y1.1
/HSE_OUT: C13.1, U2.6 (PD1), Y1.3
/I2C2_SCL: J4.2, R4.2, U2.21 (PB10)
/I2C2_SDA: J4.3, R5.2, U2.22 (PB11)
/NRST: C11.1, U2.7 (NRST)
/PWR_LED_k: D1.1 (K), R1.1
/SWCLK: J3.3, U2.37 (PA14)
/SWDIO: J3.2, U2.34 (PA13)
/SW_BOOTO: R2.1, SW1.2 (B)
/USART_RX: J2.3, U2.43 (PB7)
/USART_TX: J2.2, U2.42 (PB6)
/USB_D+: J1.3 (D+), R3.2, U2.33 (PA12)
/USB_D-: J1.2 (D-), U2.32 (PA11)
GND: C1.2, C2.2, C3.2, C4.2, C5.2, C6.2, C7.2, C8.2, C9.2, C10.2, C11.2, C12.2, C13.2, J1.5 (GND), J1.6 (Shield), J2.4, J3.4, J4.4, R1.2, SW1.1 (A), U1.1 (GND), U2.8 (VSSA), U2.23 (VSS), U2.35 (VSS), U2.47 (VSS), Y1.2, Y1.4
VBUS: C1.1, J1.1 (VBUS), U1.3 (VI)

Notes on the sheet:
CL = 2*(CL0-Cs) = 2*(10-5)pF = 10pF
MOUNTING HOLE
VDDA_FILTERING
USB_APP_NOTE AN4879
VBUS from USB connector (NOM, +5V) Min. 22uF inp./outp. caps
STM32BASE_DESIGN
POWER_SUPPLY
PIN_OUT_USING_STM32CUBEIDE
MICROCONTROLLER WITH USB

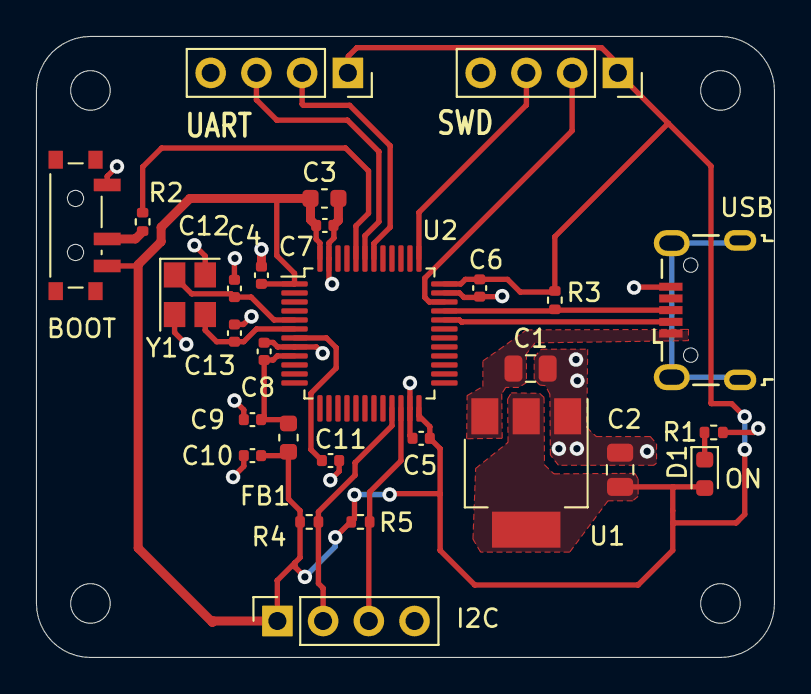
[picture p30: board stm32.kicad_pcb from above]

Board: 2 copper layers, 41.0 x 34.5 mm, 32 parts (0 on the bottom side), 18 nets.

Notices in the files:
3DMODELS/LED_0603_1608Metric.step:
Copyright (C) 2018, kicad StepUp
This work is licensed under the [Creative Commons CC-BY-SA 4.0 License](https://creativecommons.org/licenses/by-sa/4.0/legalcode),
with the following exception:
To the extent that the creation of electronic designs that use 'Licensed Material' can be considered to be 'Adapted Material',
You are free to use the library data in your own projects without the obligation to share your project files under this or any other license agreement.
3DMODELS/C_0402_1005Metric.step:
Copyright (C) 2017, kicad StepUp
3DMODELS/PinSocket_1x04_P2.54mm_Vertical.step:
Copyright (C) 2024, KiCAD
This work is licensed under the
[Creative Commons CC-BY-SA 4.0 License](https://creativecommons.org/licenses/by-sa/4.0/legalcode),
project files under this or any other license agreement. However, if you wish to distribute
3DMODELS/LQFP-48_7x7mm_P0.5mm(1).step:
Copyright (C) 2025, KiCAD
